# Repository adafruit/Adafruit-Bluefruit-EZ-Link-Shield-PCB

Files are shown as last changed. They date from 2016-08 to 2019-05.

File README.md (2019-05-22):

## Adafruit Bluefruit EZ Link Shield PCB
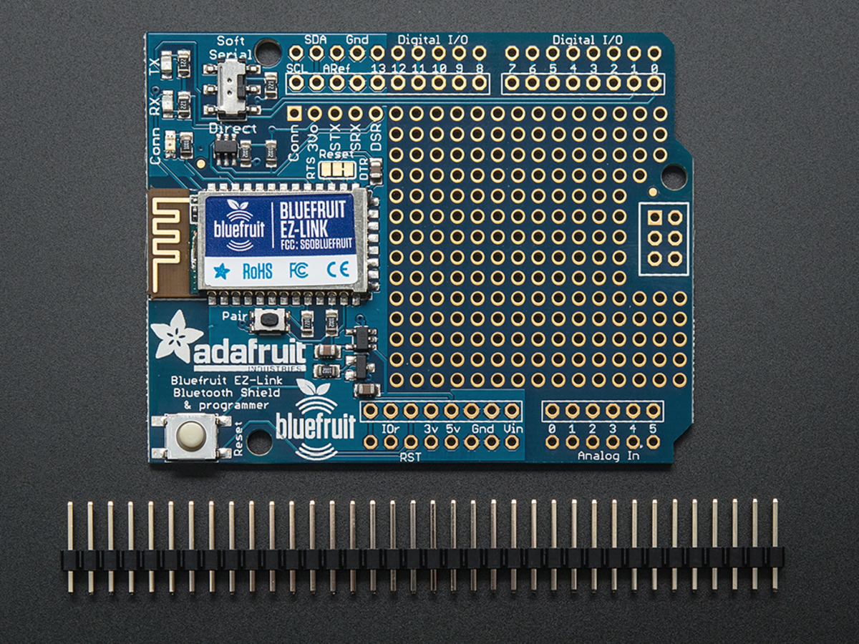
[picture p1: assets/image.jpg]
<a href="http://www.adafruit.com/products/1628"><br/>
Click here to see this in the Adafruit shop</a>

**Note: Discontinued - this product is currently undergoing a revision and will be available again soon!**

The Bluefruit EZ-Link shield is a regular 'SPP' serial link client device, that can pair with any computer or tablet and appear as a serial/COM port (except iOS as iOS does not permit SPP pairing). But here is where it gets exciting: unlike any other BT module, the EZ-Link can automatically detect and change the serial baud rate. That means if you open up the COM port on your computer at 9600 baud, the output is 9600, 57600? 57600. Yep even 2400. All the most common baud rates are supported: 2400, 4800, 9600, 19200, 38400, 57600, 115200 and 230400. You never have to configure or customize the module by hand - it all happens completely automatically inside the RF module.

PCB files for the Adafruit Bluefruit EZ-Link Shield. The format is EagleCAD schematic and board layout
- https://www.adafruit.com/product/1628

### License

Adafruit invests time and resources providing this open source design, please support Adafruit and open-source hardware by purchasing products from [Adafruit](https://www.adafruit.com)!

All text above must be included in any redistribution

Designed by Limor Fried/Ladyada for Adafruit Industries.
Creative Commons Attribution/Share-Alike, all text above must be included in any redistribution. 
See license.txt for additional information.

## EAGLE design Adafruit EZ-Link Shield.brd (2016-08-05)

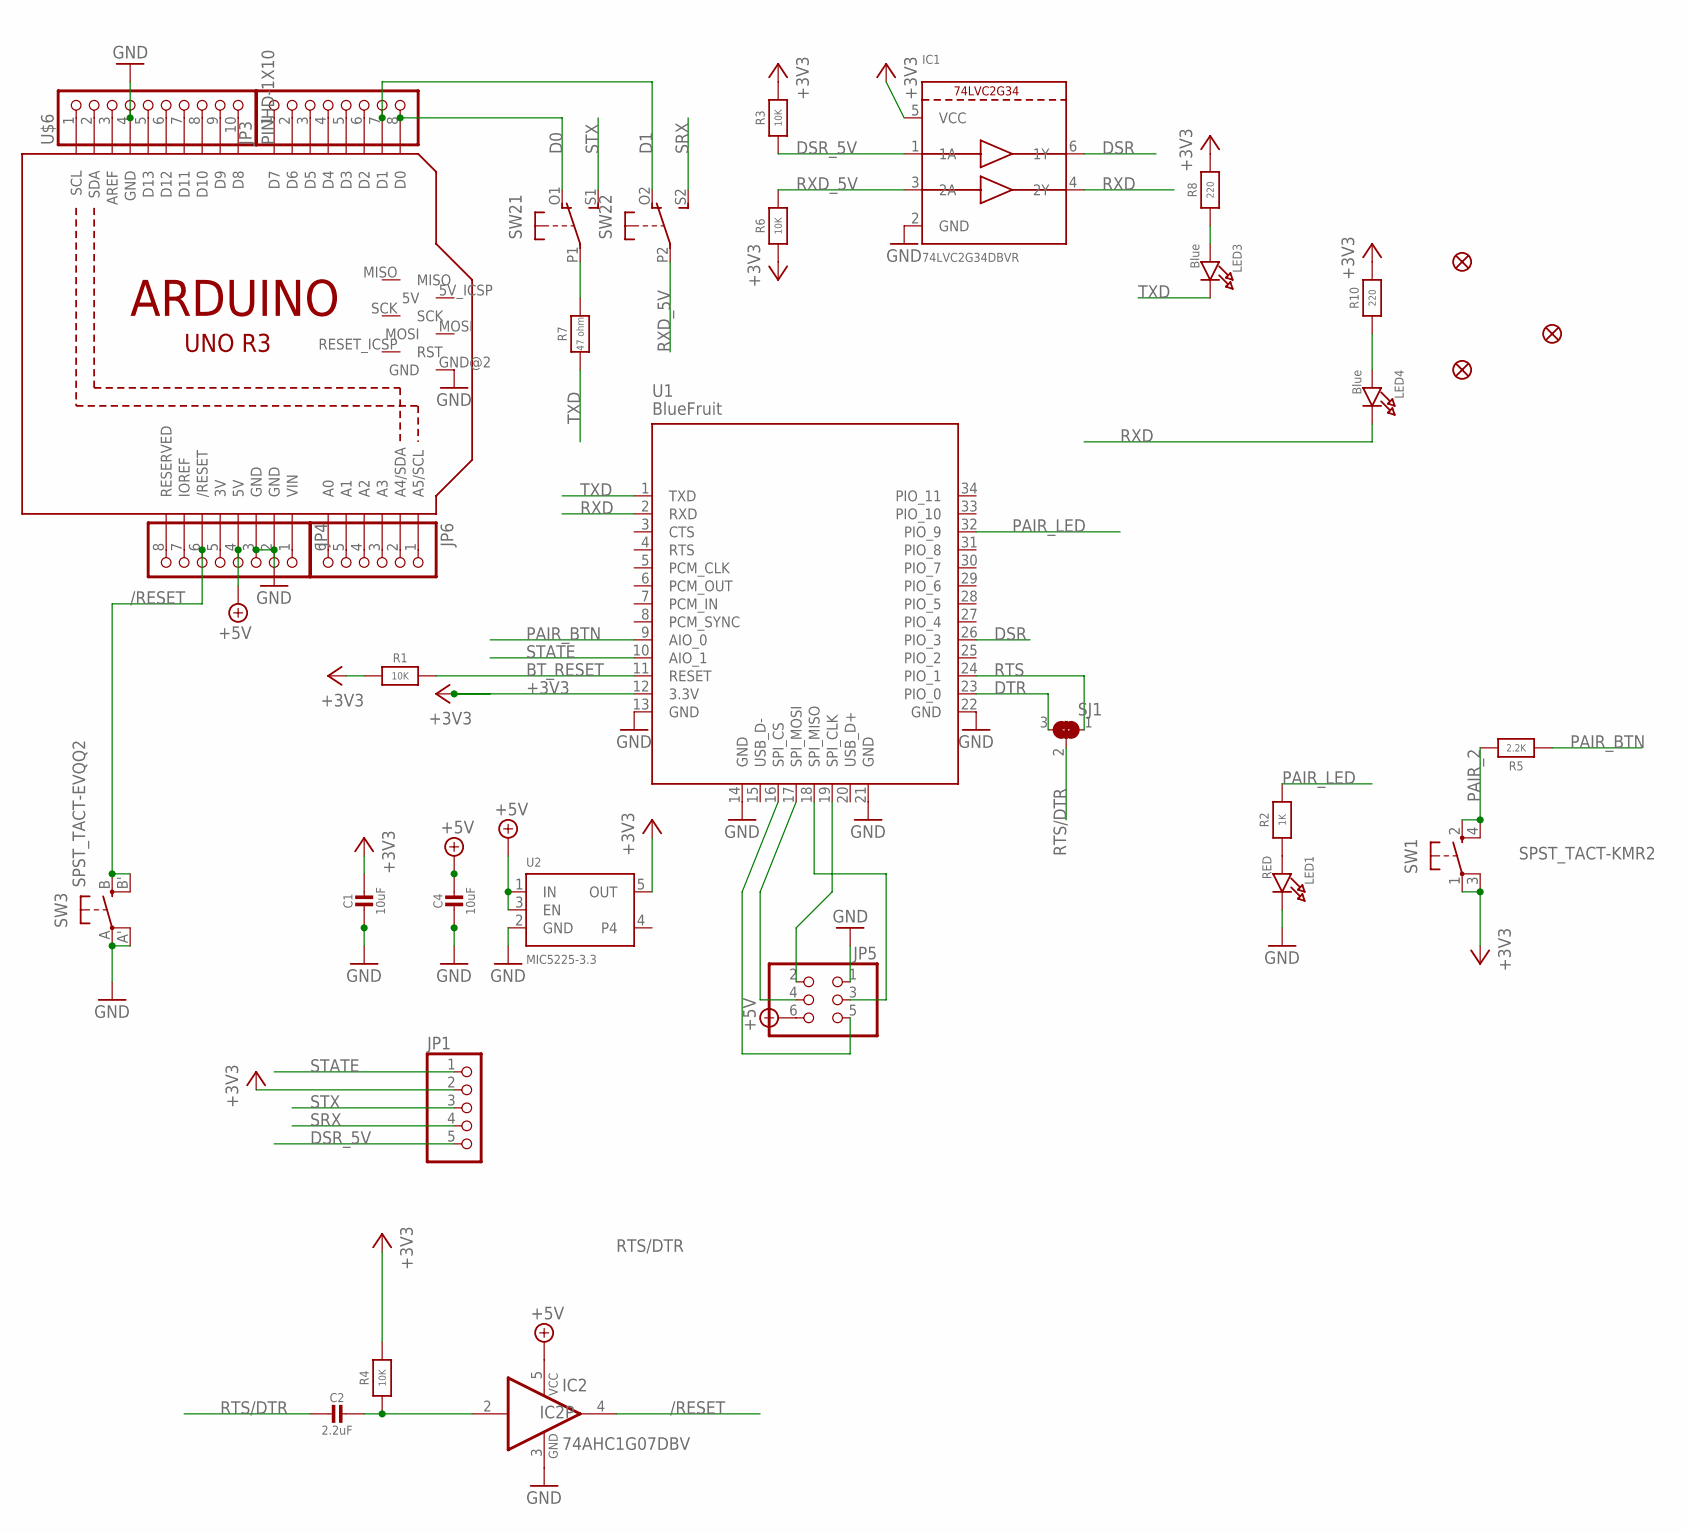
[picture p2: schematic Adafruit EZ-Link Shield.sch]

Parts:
C1, C4: 10uF; 0805-NO
C2: 2.2uF; 0805-NO
FID1, FID2, FID3: FIDUCIAL""; FIDUCIAL_1MM
IC1: 74LVC2G34DBVR; SOT23-6
IC2: 74AHC1G07DBV; SOT23-5
JP1: HEADER-1X570MIL; 1X05_ROUND_70
JP3, JP4: PINHD-1X8BIG; 1X08-BIG
JP5: HEADER-2X3; 2X03_ROUND_70MIL
JP6: PINHD-1X6B; 1X06-BIG
LED1: RED; CHIPLED_0805_NOOUTLINE
LED3, LED4: Blue; CHIPLED_0805_NOOUTLINE
R1, R4: 10K; 0805-NO
R2: 1K; 0805-NO
R3, R6: 10K; _0805MP
R5: 2.2K; 0805-NO
R7: 47 ohm; 0805-NO
R8, R10: 220; 0805-NO
SJ1: SOLDERJUMPER_2WAY; SOLDERJUMPER_2WAY_OPEN_NOPASTE
SW1: SPST_TACT-KMR2; KMR2
SW2: DPDT-EG1390; EG1390
SW3: SPST_TACT-EVQQ2; EVQ-Q2
U1: BlueFruit; BLUETOOTH_MODULE
U2: MIC5225-3.3; SOT23-5
U$5: ARDUINO_R3_ICSP; ARDUINOR3_ICSP
U$6: PINHD-1X10; 1X10-BIG

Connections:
+3V3: C1.1, IC1.5 (VCC), JP1.2, R1.1, R3.2, R4.2, R6.1, R8.2, R10.2, SW1.1, SW1.3 (P1), U1.12 (3.3V), U2.5 (OUT)
+5V: C4.1, IC2.5 (VCC), JP4.4, JP5.6, U2.1 (IN), U2.3 (EN), U$5.5V
/RESET: IC2.4 (O), JP4.6, SW3.B (S), SW3.B' (S1), U$5.RESET (/RESET)
BT_RESET: R1.2, U1.11 (RESET)
D0: JP3.8, SW2.O1 (O), U$5.D0
D1: JP3.7, SW2.O2 (O), U$5.D1
DSR: IC1.6 (1Y), U1.26 (PIO_3)
DSR_5V: IC1.1 (1A), JP1.5, R3.1
DTR: SJ1.3, U1.23 (PIO_0)
GND: C1.2, C4.2, IC1.2 (GND), IC2.3 (GND), JP4.2, JP4.3, JP5.1, LED1.C, SW3.A, SW3.A' (P1), U1.13 (GND), U1.14 (GND), U1.21 (GND), U1.22 (GND), U2.2 (GND), U$5.GND, U$5.GND@1 (GND), U$5.GND@2 (GND), U$5.GND@3 (GND), U$6.4
unnamed: C2.1, IC2.2 (I), R4.1
unnamed: LED1.A, R2.1
unnamed: R7.2, SW2.P1
unnamed: JP3.1, U$5.D7
unnamed: JP3.2, U$5.D6
unnamed: LED3.A, R8.1
unnamed: JP3.3, U$5.D5
unnamed: JP3.4, U$5.D4
unnamed: LED4.A, R10.1
unnamed: JP3.5, U$5.D3
unnamed: JP3.6, U$5.D2
unnamed: JP4.1, U$5.VIN
unnamed: JP4.5, U$5.3V
unnamed: JP4.7, U$5.IOREF
unnamed: JP4.8, U$5.RESERVED
unnamed: JP6.1, U$5.A5 (A5/SCL)
unnamed: JP6.2, U$5.A4 (A4/SDA)
unnamed: JP6.3, U$5.A3
unnamed: JP6.4, U$5.A2
unnamed: JP6.5, U$5.A1
unnamed: JP6.6, U$5.A0
unnamed: U$5.SCL, U$6.1
unnamed: U$5.SDA, U$6.2
unnamed: U$5.AREF, U$6.3
unnamed: U$5.D13, U$6.5
unnamed: U$5.D12, U$6.6
unnamed: U$5.D11, U$6.7
unnamed: U$5.D10, U$6.8
unnamed: U$5.D9, U$6.9
unnamed: U$5.D8, U$6.10
PAIR_2: R5.2, SW1.2 (S), SW1.4 (S1)
PAIR_BTN: R5.1, U1.9 (AIO_0)
PAIR_LED: R2.2, U1.32 (PIO_9)
RTS: SJ1.1, U1.24 (PIO_1)
RTS/DTR: C2.2, SJ1.2
RXD: IC1.4 (2Y), LED4.C, U1.2 (RXD)
RXD_5V: IC1.3 (2A), R6.2, SW2.P2
SPI_CLK: JP5.2, U1.19 (SPI_CLK)
SPI_CS: JP5.5, U1.16 (SPI_CS)
SPI_MISO: JP5.3, U1.18 (SPI_MISO)
SPI_MOSI: JP5.4, U1.17 (SPI_MOSI)
SRX: JP1.4, SW2.S2 (S)
STATE: JP1.1, U1.10 (AIO_1)
STX: JP1.3, SW2.S1 (S)
TXD: LED3.C, R7.1, U1.1 (TXD)

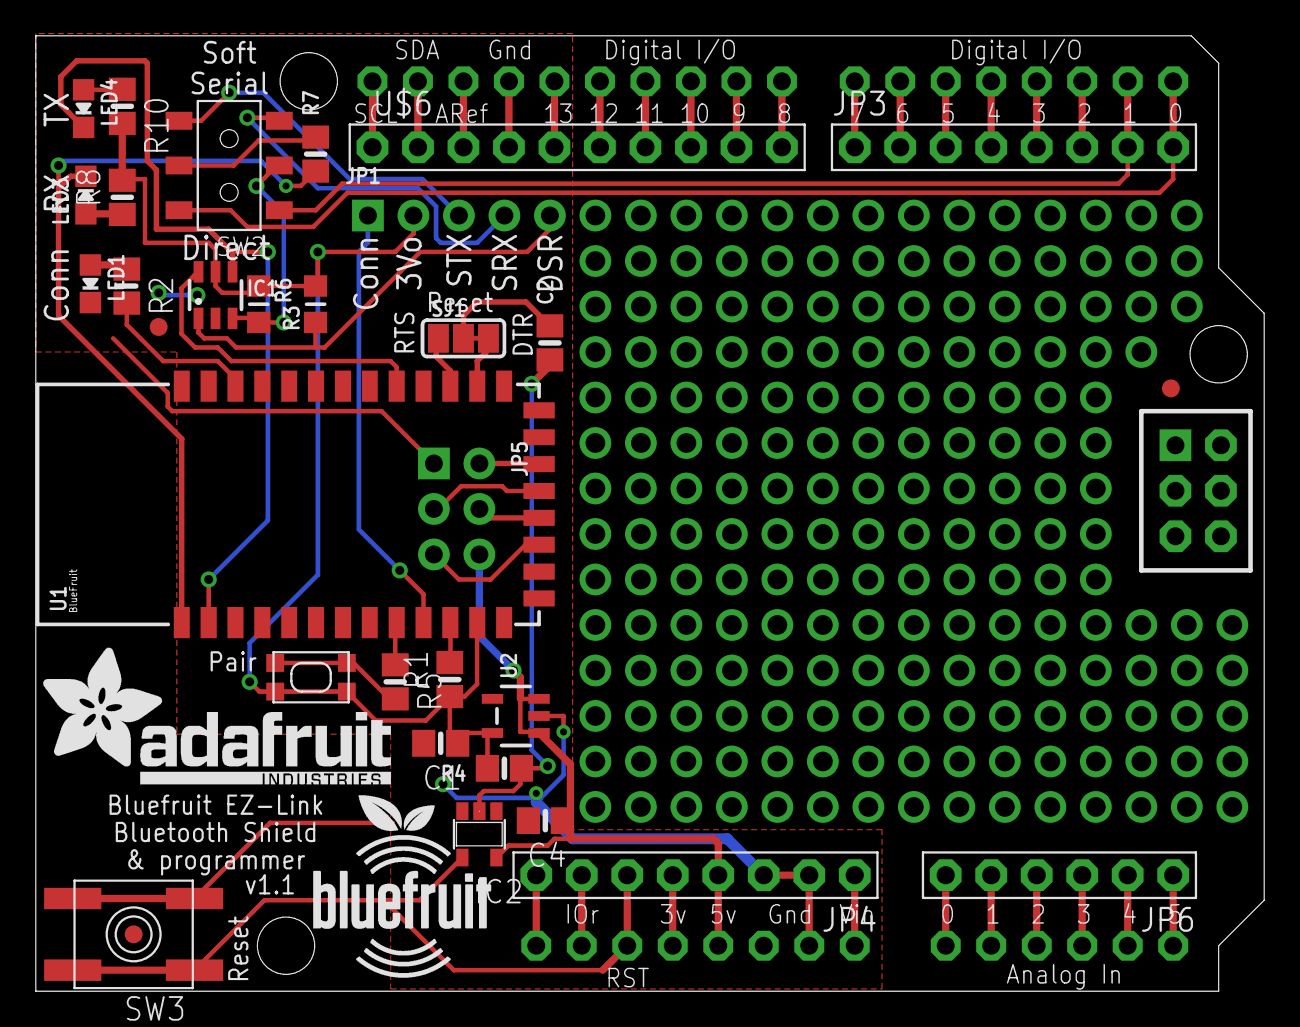
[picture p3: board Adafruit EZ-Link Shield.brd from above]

Board: 2 copper layers, 68.6 x 53.3 mm, 35 parts (0 on the bottom side), 55 nets.

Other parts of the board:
U$4: BLUEFRUITLOGO_100MM
U$7: ADAFRUIT_TEXT_20MM
